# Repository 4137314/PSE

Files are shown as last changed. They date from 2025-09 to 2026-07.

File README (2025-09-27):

PSE - Power Supply Emulator
===========================

Version: 1.0
Author: 4137314
License: GNU General Public License v3.0

Purpose
-------
PSE is a KiCad project designed to emulate power supply circuits
for testing and prototyping purposes. It includes both schematic
and PCB layout files suitable for educational and development use.

Installation
------------
To obtain the project, clone the repository using Git:

    git clone https://github.com/4137314/PSE.git
    cd PSE

Open the file "PSE.kicad_pro" in KiCad to access the full project.

Usage
-----
- Inspect the schematic via "PSE.kicad_sch".
- Review the PCB layout in "PSE.kicad_pcb".
- Generate manufacturing files (Gerber, BOM, Drill) if needed.

Ensure all libraries and footprints referenced by the project are
available in your KiCad environment.

License
-------
This project is licensed under the GNU General Public License v3.0.
Refer to the LICENSE file in this repository for the full license text.

Reporting Bugs / Contributing
-----------------------------
Report bugs or suggest improvements via GitHub Issues. Contributions
are welcome under the same GPLv3 license.

Contact
-------
4137314
https://github.com/4137314/PSE

=======================================================================

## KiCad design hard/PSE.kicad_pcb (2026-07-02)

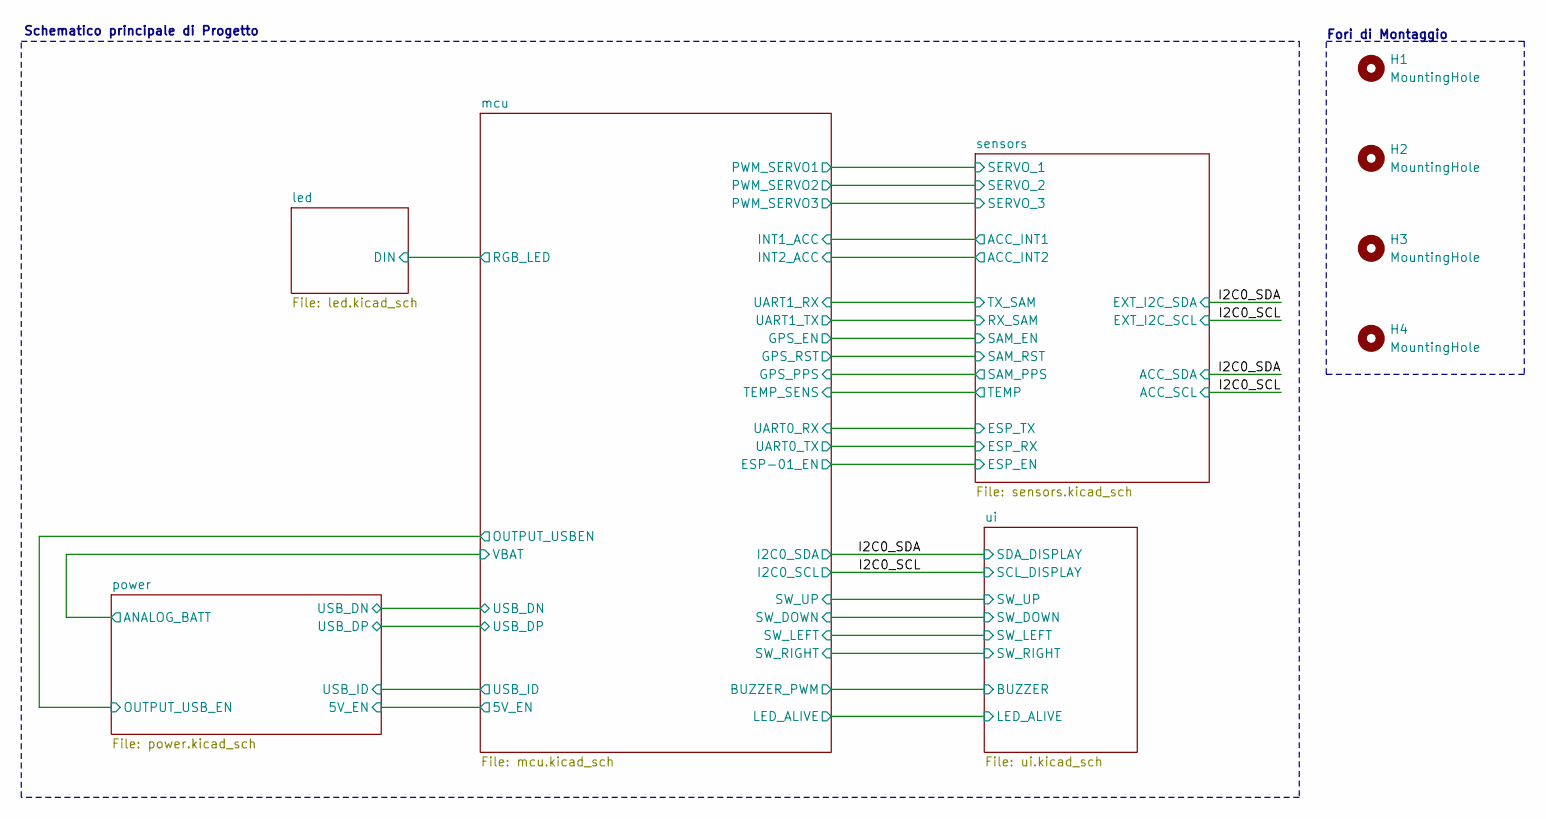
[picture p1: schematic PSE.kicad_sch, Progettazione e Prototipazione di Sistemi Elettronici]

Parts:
H1, H2, H3, H4: MountingHole; MountingHole_3.2mm_M3_Pad_Via

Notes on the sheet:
Fori di Montaggio
Schematico principale di Progetto

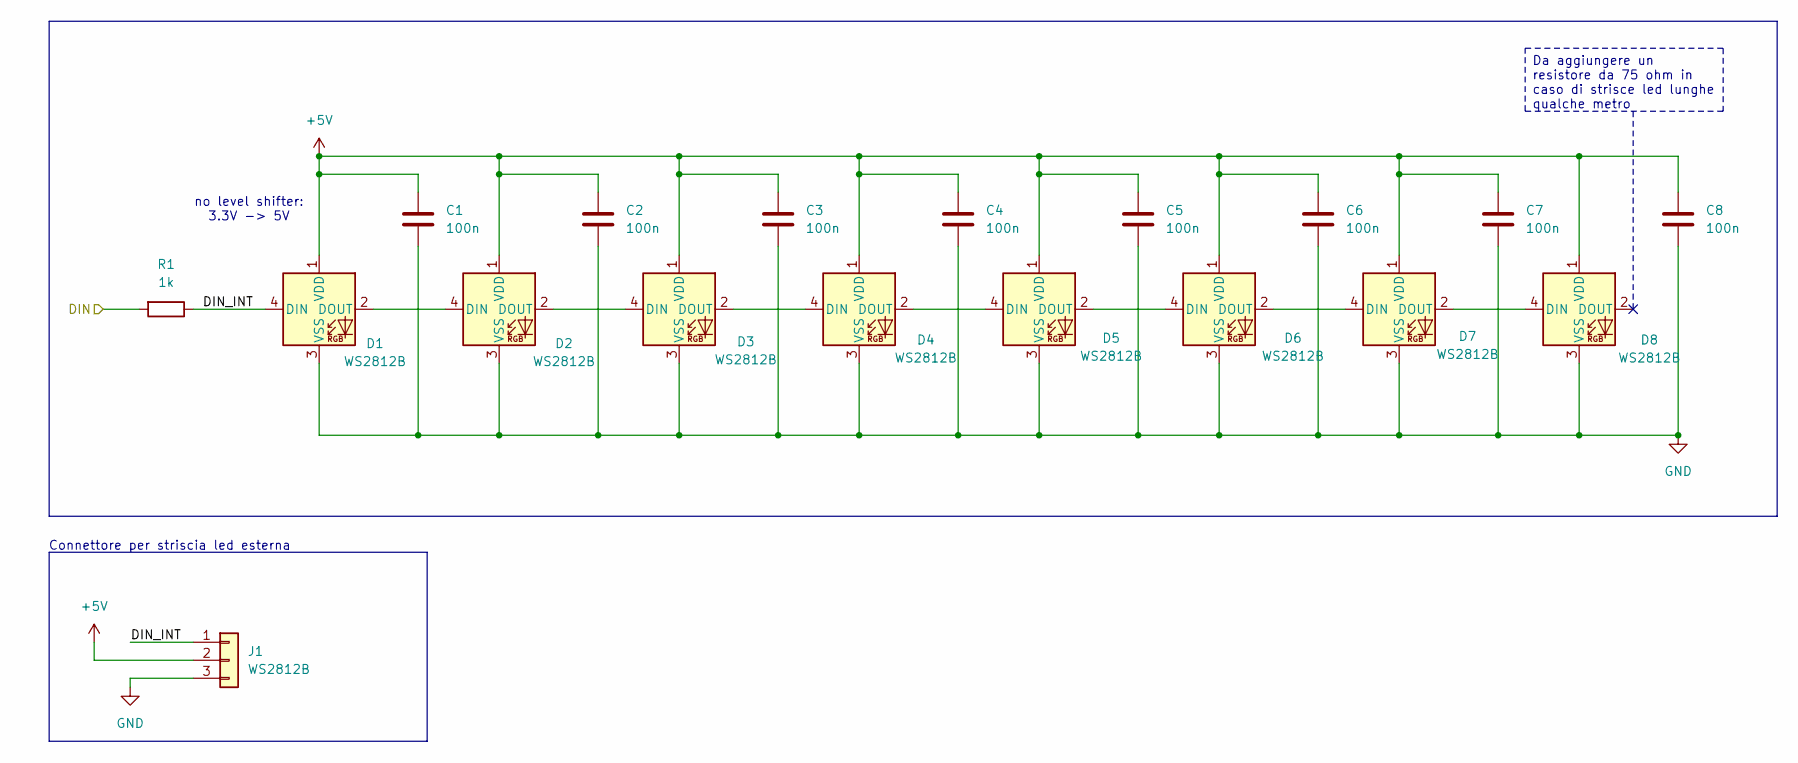
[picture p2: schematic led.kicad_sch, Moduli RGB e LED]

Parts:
C1, C2, C3, C4, C5, C6, C7, C8: 100n; C_0603_1608Metric
D1, D2, D3, D4, D5, D6, D7, D8: WS2812B; LED_WS2812B_PLCC4_5.0x5.0mm_P3.2mm
J1: WS2812B; PinHeader_1x03_P2.54mm_Vertical
R1: 1k; R_0603_1608Metric

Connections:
+5V: C1.1, C2.1, C3.1, C4.1, C5.1, C6.1, C7.1, C8.1, D1.1 (VDD), D2.1 (VDD), D3.1 (VDD), D4.1 (VDD), D5.1 (VDD), D6.1 (VDD), D7.1 (VDD), D8.1 (VDD), J1.2; also elsewhere on the board
/led/DIN: R1.2; also elsewhere on the board
/led/DIN_INT: D1.4 (DIN), J1.1, R1.1
GND: C1.2, C2.2, C3.2, C4.2, C5.2, C6.2, C7.2, C8.2, D1.3 (VSS), D2.3 (VSS), D3.3 (VSS), D4.3 (VSS), D5.3 (VSS), D6.3 (VSS), D7.3 (VSS), D8.3 (VSS), J1.3; also elsewhere on the board
unnamed: D1.2 (DOUT), D2.4 (DIN)
unnamed: D2.2 (DOUT), D3.4 (DIN)
unnamed: D3.2 (DOUT), D4.4 (DIN)
unnamed: D4.2 (DOUT), D5.4 (DIN)
unnamed: D5.2 (DOUT), D6.4 (DIN)
unnamed: D6.2 (DOUT), D7.4 (DIN)
unnamed: D7.2 (DOUT), D8.4 (DIN)

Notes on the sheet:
no level shifter: 3.3V -> 5V
Connettore per striscia led esterna
Da aggiungere un resistore da 75 ohm in caso di strisce led lunghe qualche metro

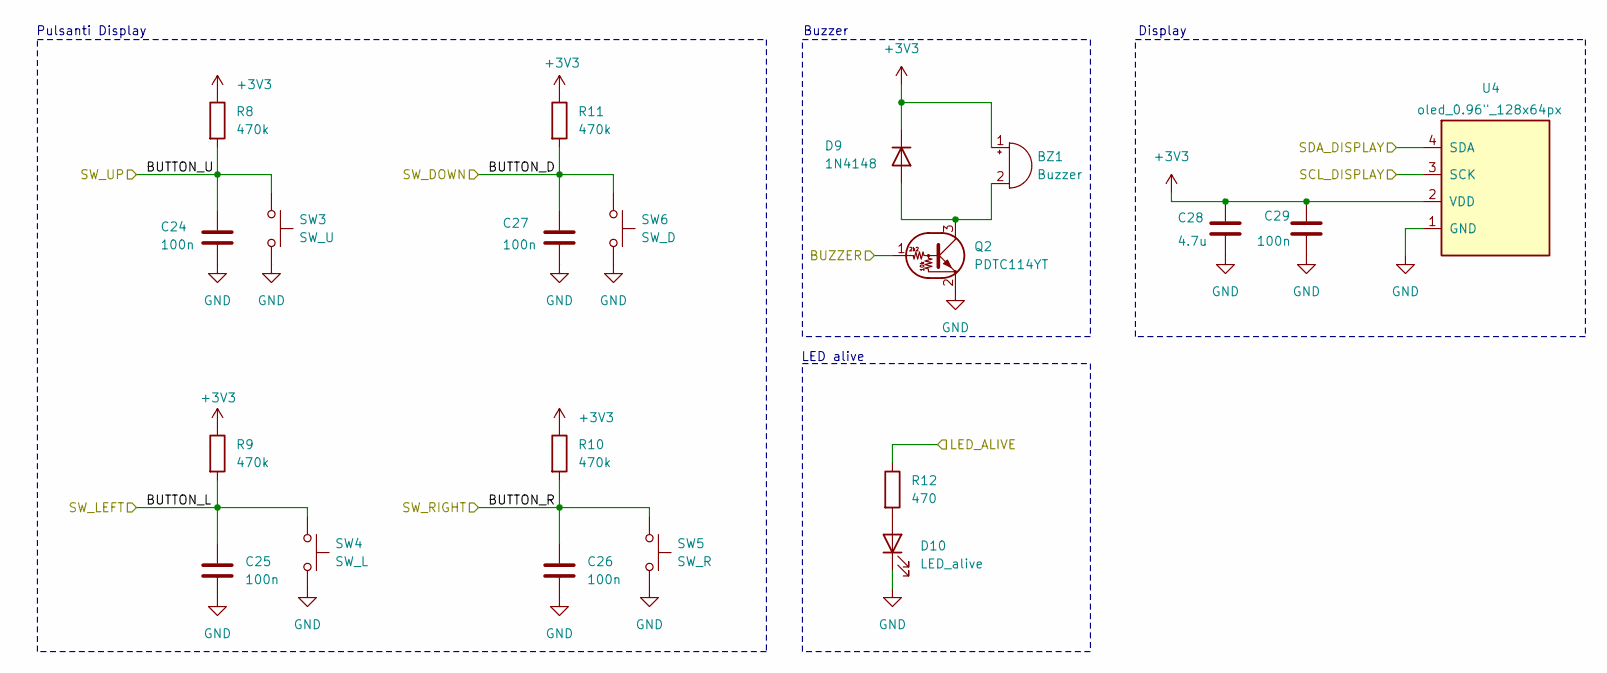
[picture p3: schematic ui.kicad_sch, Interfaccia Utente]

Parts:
BZ1: Buzzer; Buzzer_12x9.5RM7.6
C24, C25, C26, C27, C29: 100n; C_0603_1608Metric
C28: 4.7u; C_0603_1608Metric
D9: 1N4148; D_SOD-123
D10: LED_alive; LED_0603_1608Metric
Q2: PDTC114YT; SOT-23
R8, R9, R10, R11: 470k; R_0603_1608Metric
R12: 470; R_0603_1608Metric
SW3: SW_U; SW_SPST_EVQP0
SW4: SW_L; SW_SPST_EVQP0
SW5: SW_R; SW_SPST_EVQP0
SW6: SW_D; SW_SPST_EVQP0
U4: oled_0.96"_128x64px; PinHeader_1x04_P2.54mm_Vertical

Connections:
+3V3: BZ1.1 (+), C28.1, C29.1, D9.1 (K), R8.1, R9.1, R10.1, R11.1, U4.2 (VDD); also elsewhere on the board
/I2C0_SCL: U4.3 (SCK); also elsewhere on the board
/I2C0_SDA: U4.4 (SDA); also elsewhere on the board
/mcu/BUZZER_PWM: Q2.1 (B); also elsewhere on the board
/mcu/LED_ALIVE: R12.1; also elsewhere on the board
/ui/BUTTON_D: C27.1, R11.2, SW6.1; also elsewhere on the board
/ui/BUTTON_L: C25.1, R9.2, SW4.1; also elsewhere on the board
/ui/BUTTON_R: C26.1, R10.2, SW5.1; also elsewhere on the board
/ui/BUTTON_U: C24.1, R8.2, SW3.1; also elsewhere on the board
GND: C24.2, C25.2, C26.2, C27.2, C28.2, C29.2, D10.1 (K), Q2.2 (E), SW3.2, SW4.2, SW5.2, SW6.2, U4.1 (GND); also elsewhere on the board
unnamed: BZ1.2 (-), D9.2 (A), Q2.3 (C)
unnamed: D10.2 (A), R12.2

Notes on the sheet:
Pulsanti Display
Buzzer
Display
LED alive

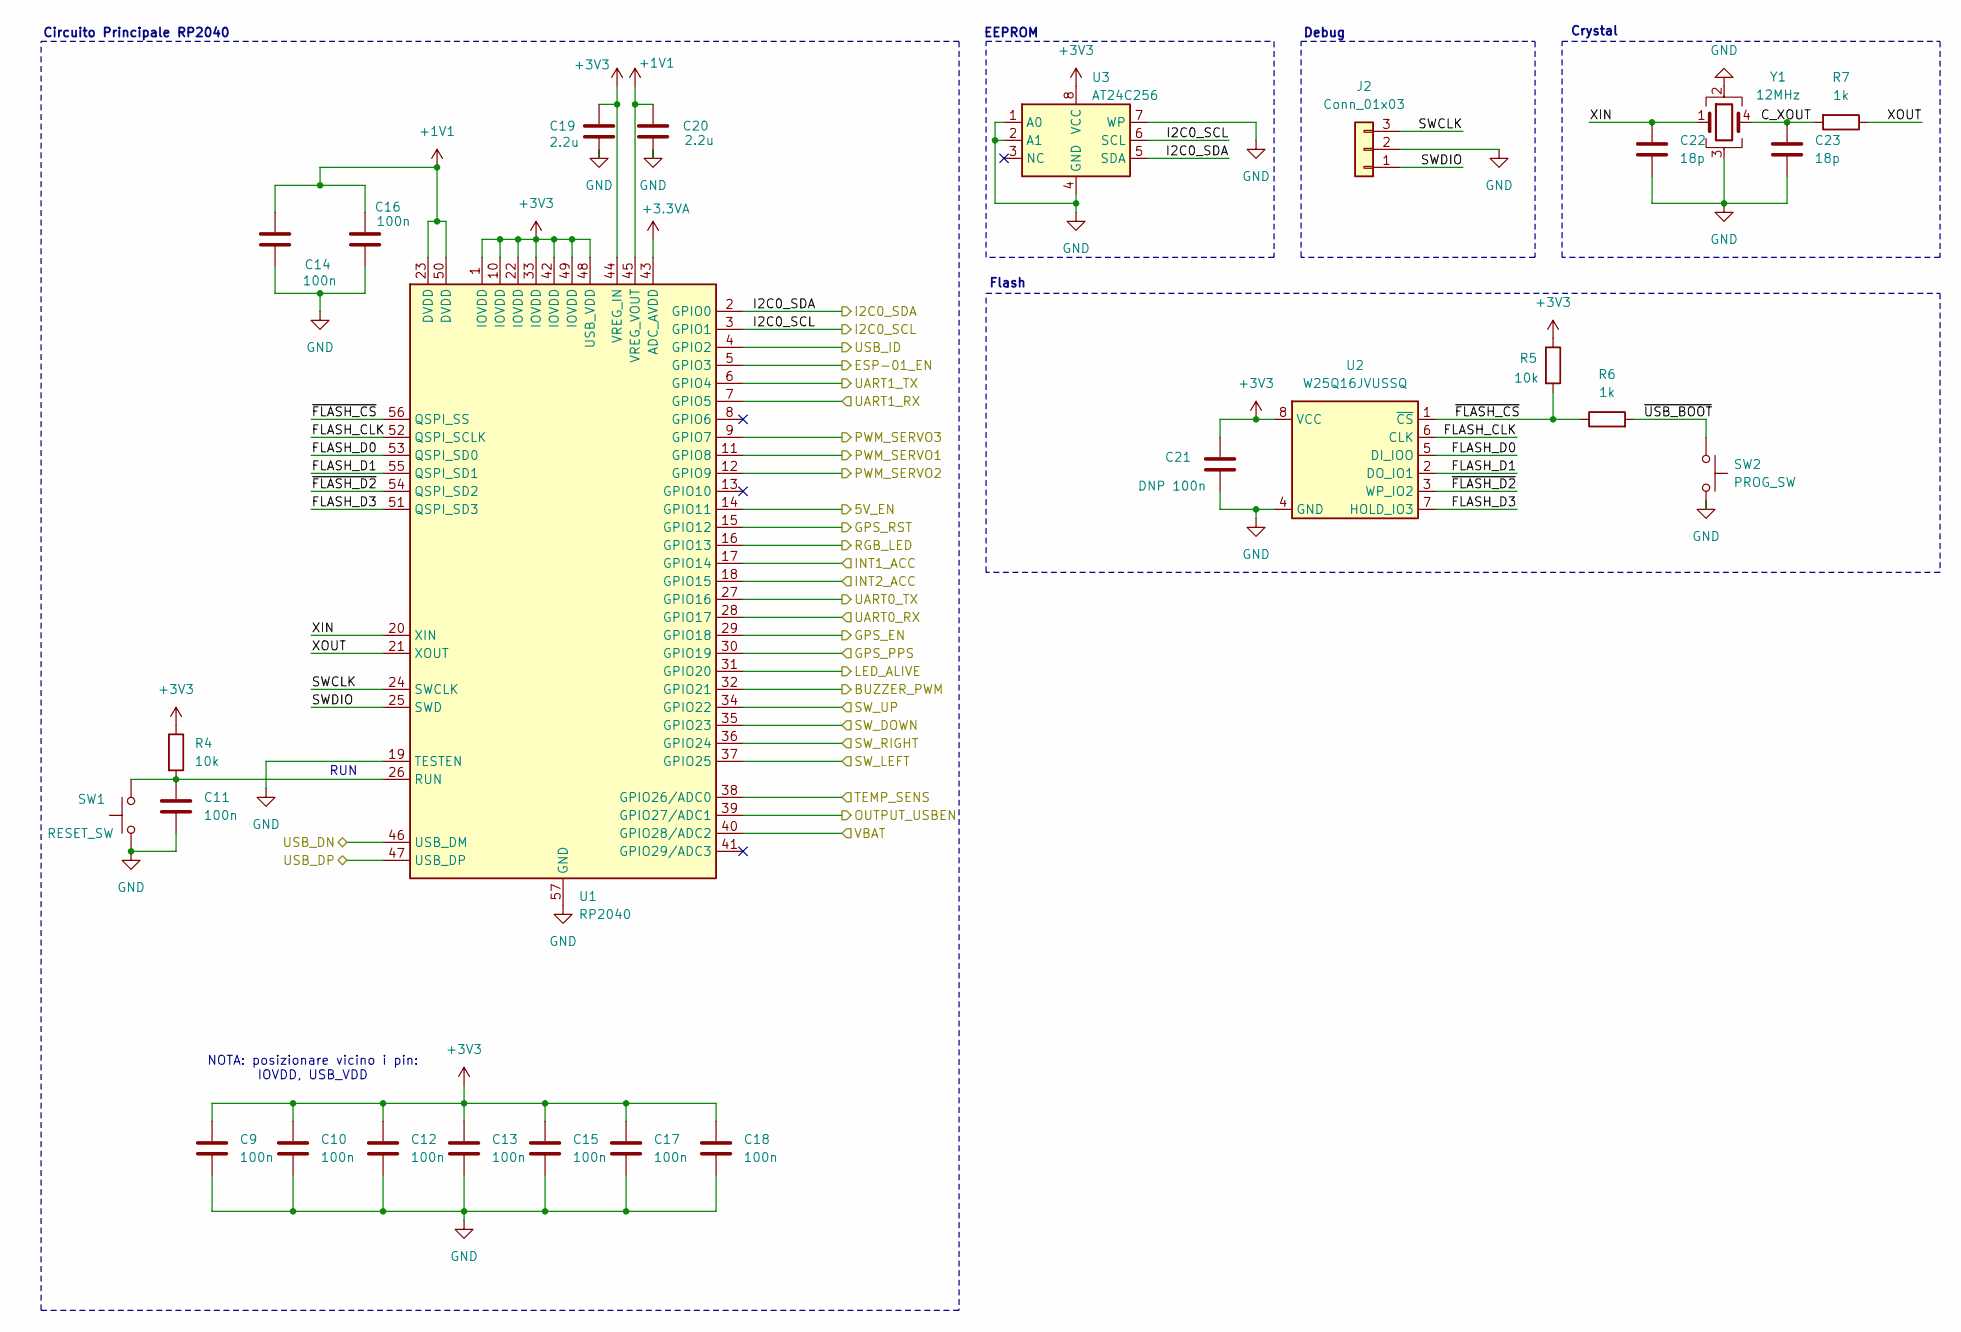
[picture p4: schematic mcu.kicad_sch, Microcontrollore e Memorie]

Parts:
C9, C10, C11, C12, C13, C14, C15, C16, C17, C18: 100n; C_0603_1608Metric
C19, C20: 2.2u; C_0603_1608Metric
C21: DNP 100n; C_0603_1608Metric
C22, C23: 18p; C_0603_1608Metric
J2: Conn_01x03; PinHeader_1x03_P2.54mm_Vertical
R4, R5: 10k; R_0603_1608Metric
R6, R7: 1k; R_0603_1608Metric
SW1: RESET_SW; SW_SPST_EVQP0
SW2: PROG_SW; SW_SPST_EVQP0
U1: RP2040; QFN-56-1EP_7x7mm_P0.4mm_EP3.2x3.2mm
U2: W25Q16JVUSSQ; SOIC-8_5.3x5.3mm_P1.27mm
U3: AT24C256; SOIC-8_3.9x4.9mm_P1.27mm
Y1: 12MHz; Crystal_SMD_3225-4Pin_3.2x2.5mm_HandSoldering

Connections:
+1V1: C14.1, C16.1, C20.1, U1.23 (DVDD), U1.45 (VREG_VOUT), U1.50 (DVDD)
+3.3VA: U1.43 (ADC_AVDD); also elsewhere on the board
+3V3: C9.1, C10.1, C12.1, C13.1, C15.1, C17.1, C18.1, C19.1, C21.1, R4.1, R5.1, U1.1 (IOVDD), U1.10 (IOVDD), U1.22 (IOVDD), U1.33 (IOVDD), U1.42 (IOVDD), U1.44 (VREG_IN), U1.48 (USB_VDD), U1.49 (IOVDD), U2.8 (VCC), U3.8 (VCC); also elsewhere on the board
/I2C0_SCL: U1.3 (GPIO1), U3.6 (SCL); also elsewhere on the board
/I2C0_SDA: U1.2 (GPIO0), U3.5 (SDA); also elsewhere on the board
/led/DIN: U1.16 (GPIO13); also elsewhere on the board
/mcu/5V_EN: U1.14 (GPIO11); also elsewhere on the board
/mcu/BUZZER_PWM: U1.32 (GPIO21); also elsewhere on the board
/mcu/C_XOUT: C23.1, R7.2, Y1.4
/mcu/ESP-01_EN: U1.5 (GPIO3); also elsewhere on the board
/mcu/FLASH_CLK: U1.52 (QSPI_SCLK), U2.6 (CLK)
/mcu/FLASH_D0: U1.53 (QSPI_SD0), U2.5 (DI_IOO)
/mcu/FLASH_D1: U1.55 (QSPI_SD1), U2.2 (DO_IO1)
/mcu/FLASH_D3: U1.51 (QSPI_SD3), U2.7 (HOLD_IO3)
/mcu/GPS_EN: U1.29 (GPIO18); also elsewhere on the board
/mcu/GPS_PPS: U1.30 (GPIO19); also elsewhere on the board
/mcu/GPS_RST: U1.15 (GPIO12); also elsewhere on the board
/mcu/INT1_ACC: U1.17 (GPIO14); also elsewhere on the board
/mcu/INT2_ACC: U1.18 (GPIO15); also elsewhere on the board
/mcu/LED_ALIVE: U1.31 (GPIO20); also elsewhere on the board
/mcu/OUTPUT_USBEN: U1.39 (GPIO27/ADC1); also elsewhere on the board
/mcu/PWM_SERVO1: U1.11 (GPIO8); also elsewhere on the board
/mcu/PWM_SERVO2: U1.12 (GPIO9); also elsewhere on the board
/mcu/PWM_SERVO3: U1.9 (GPIO7); also elsewhere on the board
/mcu/SWCLK: J2.3, U1.24 (SWCLK)
/mcu/SWDIO: J2.1, U1.25 (SWD)
/mcu/TEMP_SENS: U1.38 (GPIO26/ADC0); also elsewhere on the board
/mcu/UART0_RX: U1.28 (GPIO17); also elsewhere on the board
/mcu/UART0_TX: U1.27 (GPIO16); also elsewhere on the board
/mcu/USB_DN: U1.46 (USB_DM); also elsewhere on the board
/mcu/USB_DP: U1.47 (USB_DP); also elsewhere on the board
/mcu/USB_ID: U1.4 (GPIO2); also elsewhere on the board
/mcu/VBAT: U1.40 (GPIO28/ADC2); also elsewhere on the board
/mcu/XIN: C22.1, U1.20 (XIN), Y1.1
/mcu/XOUT: R7.1, U1.21 (XOUT)
/mcu/~FLASH_CS: R5.2, R6.1, U1.56 (QSPI_SS), U2.1 (~CS)
/mcu/~FLASH_D2: U1.54 (QSPI_SD2), U2.3 (WP_IO2)
/mcu/~USB_BOOT: R6.2, SW2.1
/sensors/UART_RX: U1.7 (GPIO5); also elsewhere on the board
/sensors/UART_TX: U1.6 (GPIO4); also elsewhere on the board
/ui/BUTTON_D: U1.35 (GPIO23); also elsewhere on the board
/ui/BUTTON_L: U1.37 (GPIO25); also elsewhere on the board
/ui/BUTTON_R: U1.36 (GPIO24); also elsewhere on the board
/ui/BUTTON_U: U1.34 (GPIO22); also elsewhere on the board
GND: C9.2, C10.2, C11.2, C12.2, C13.2, C14.2, C15.2, C16.2, C17.2, C18.2, C19.2, C20.2, C21.2, C22.2, C23.2, J2.2, SW1.1, SW2.2, U1.19 (TESTEN), U1.57 (GND), U2.4 (GND), U3.1 (A0), U3.2 (A1), U3.4 (GND), U3.7 (WP), Y1.2, Y1.3; also elsewhere on the board
unnamed: C11.1, R4.2, SW1.2, U1.26 (RUN)

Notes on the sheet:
Circuito Principale RP2040
Flash
Debug
NOTA: posizionare vicino i pin: IOVDD, USB_VDD
Crystal
RUN
EEPROM

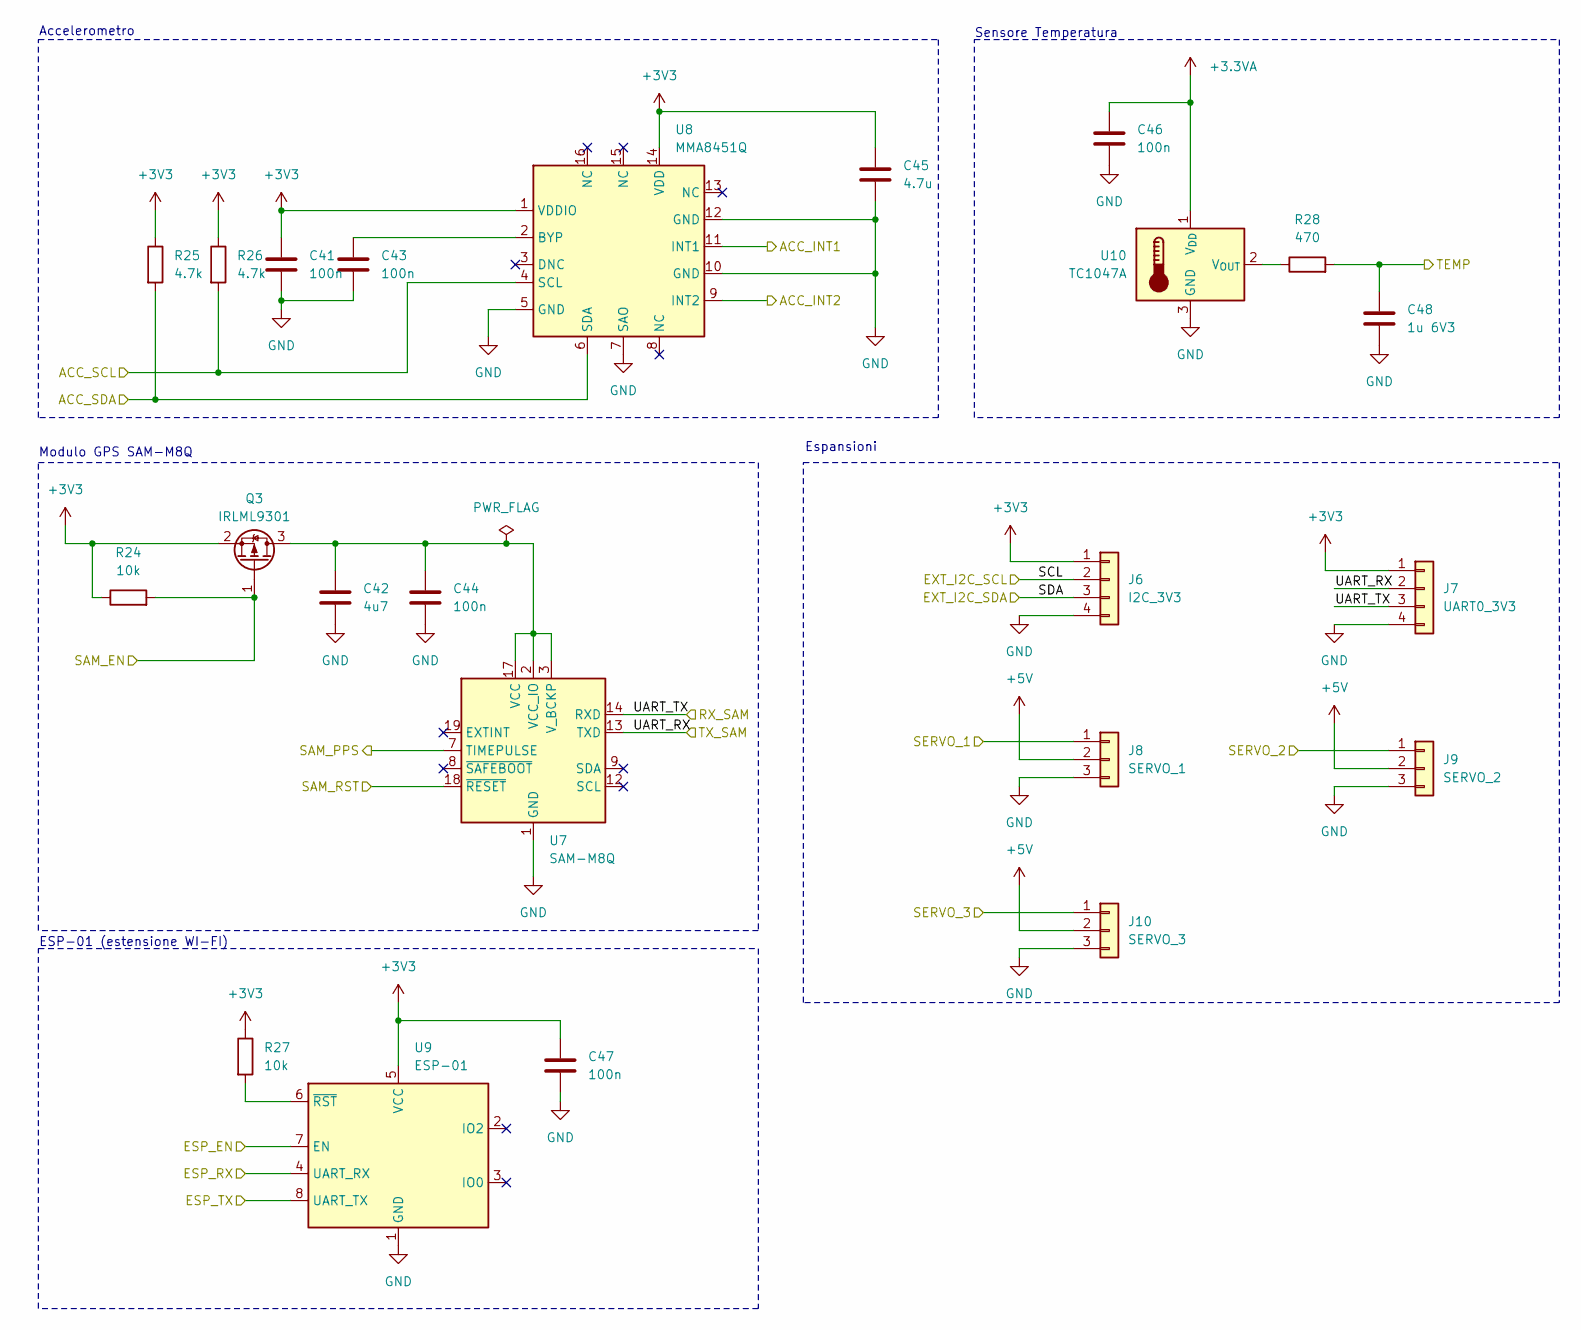
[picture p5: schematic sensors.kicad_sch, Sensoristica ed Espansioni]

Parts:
C41, C43, C44, C46, C47: 100n; C_0603_1608Metric
C42: 4u7; C_0603_1608Metric
C45: 4.7u; C_0603_1608Metric
C48: 1u 6V3; C_0603_1608Metric
J6: I2C_3V3; JST_XH_B4B-XH-A_1x04_P2.50mm_Vertical
J7: UART0_3V3; JST_XH_B4B-XH-A_1x04_P2.50mm_Vertical
J8: SERVO_1; PinHeader_1x03_P2.54mm_Vertical
J9: SERVO_2; PinHeader_1x03_P2.54mm_Vertical
J10: SERVO_3; PinHeader_1x03_P2.54mm_Vertical
Q3: IRLML9301; SOT-23
R24, R27: 10k; R_0603_1608Metric
R25, R26: 4.7k; R_0603_1608Metric
R28: 470; R_0603_1608Metric
U7: SAM-M8Q; ublox_SAM-M8Q
U8: MMA8451Q; QFN16_FRE
U9: ESP-01; PinSocket_2x04_P2.54mm_Vertical
U10: TC1047A; SOT-23

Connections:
+3.3VA: C46.1, U10.1 (V_{DD}); also elsewhere on the board
+3V3: C41.1, C45.1, C47.1, J6.1, J7.1, Q3.2 (S), R24.1, R25.1, R26.1, R27.1, U8.1 (VDDIO), U8.14 (VDD), U9.5 (VCC); also elsewhere on the board
+5V: J8.2, J9.2, J10.2; also elsewhere on the board
/I2C0_SCL: J6.2, R26.2, U8.4 (SCL); also elsewhere on the board
/I2C0_SDA: J6.3, R25.2, U8.6 (SDA); also elsewhere on the board
/mcu/ESP-01_EN: U9.7 (EN); also elsewhere on the board
/mcu/GPS_EN: Q3.1 (G), R24.2; also elsewhere on the board
/mcu/GPS_PPS: U7.7 (TIMEPULSE); also elsewhere on the board
/mcu/GPS_RST: U7.18 (~RESET); also elsewhere on the board
/mcu/INT1_ACC: U8.11 (INT1); also elsewhere on the board
/mcu/INT2_ACC: U8.9 (INT2); also elsewhere on the board
/mcu/PWM_SERVO1: J8.1; also elsewhere on the board
/mcu/PWM_SERVO2: J9.1; also elsewhere on the board
/mcu/PWM_SERVO3: J10.1; also elsewhere on the board
/mcu/TEMP_SENS: C48.1, R28.2; also elsewhere on the board
/mcu/UART0_RX: U9.8 (UART_TX); also elsewhere on the board
/mcu/UART0_TX: U9.4 (UART_RX); also elsewhere on the board
/sensors/UART_RX: J7.2, U7.13 (TXD); also elsewhere on the board
/sensors/UART_TX: J7.3, U7.14 (RXD); also elsewhere on the board
GND: C41.2, C42.2, C43.2, C44.2, C45.2, C46.2, C47.2, C48.2, J6.4, J7.4, J8.3, J9.3, J10.3, U7.1 (GND), U8.5 (GND), U8.7 (SAO), U8.10 (GND), U8.12 (GND), U9.1 (GND), U10.3 (GND); also elsewhere on the board
unnamed: C42.1, C44.1, Q3.3 (D), U7.2 (VCC_IO), U7.3 (V_BCKP), U7.17 (VCC)
unnamed: C43.1, U8.2 (BYP)
unnamed: R27.2, U9.6 (~RST)
unnamed: R28.1, U10.2 (V_{OUT})

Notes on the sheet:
Sensore Temperatura
Accelerometro
ESP-01 (estensione WI-FI)
Modulo GPS SAM-M8Q
Espansioni

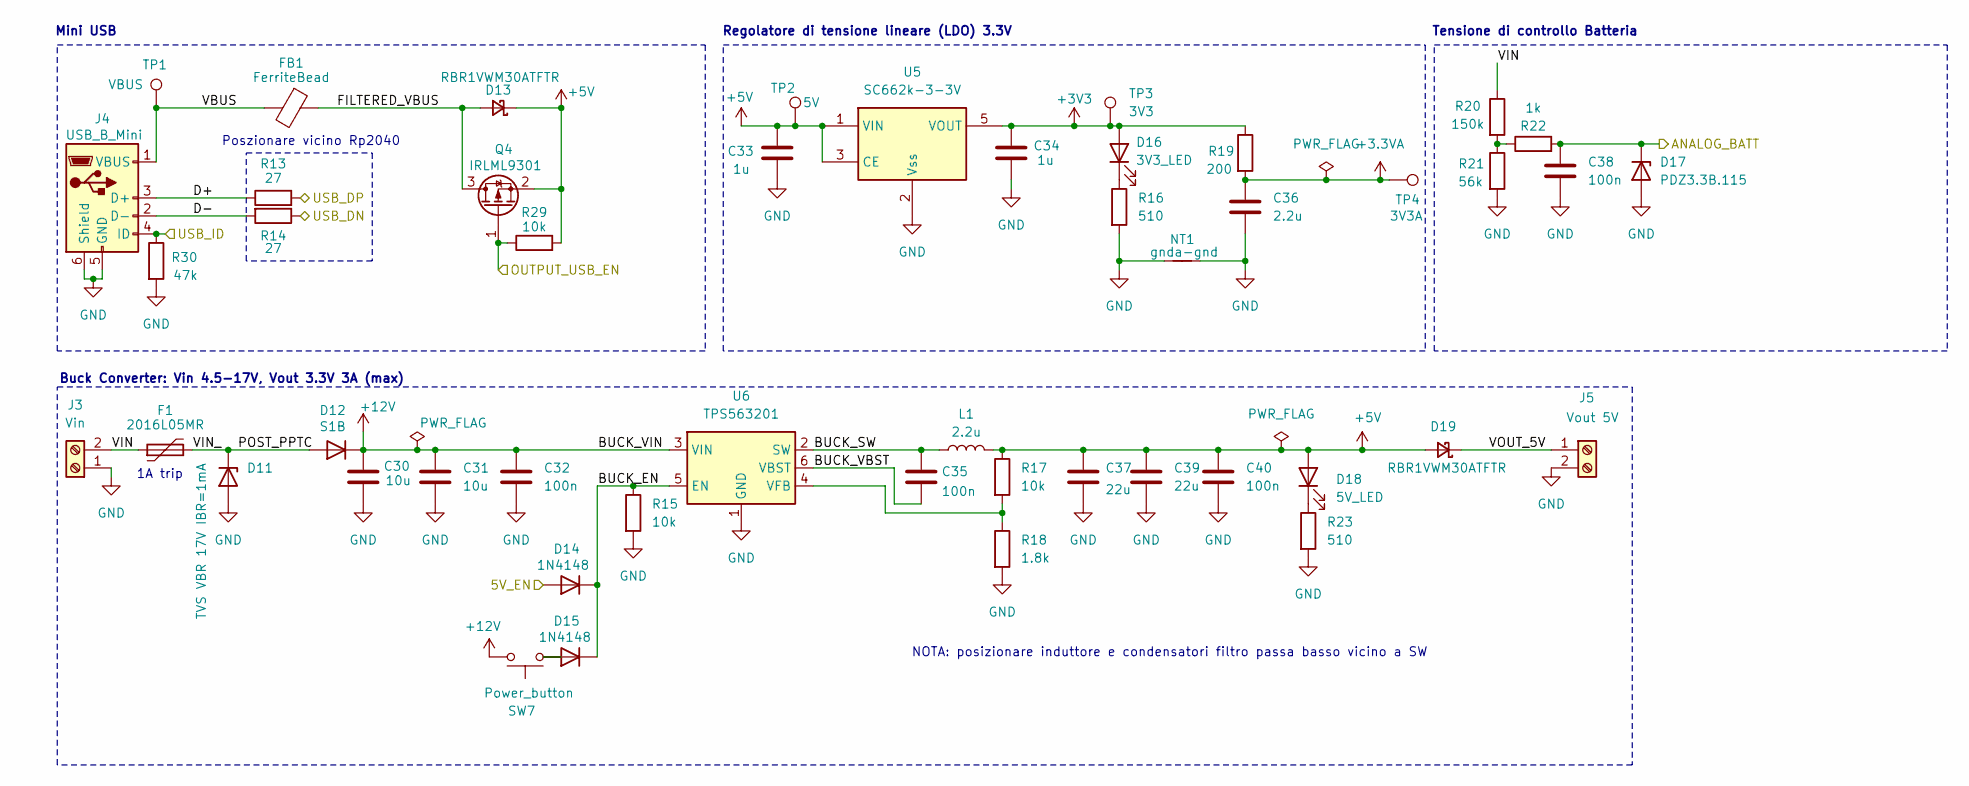
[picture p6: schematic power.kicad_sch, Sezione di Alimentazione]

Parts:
C30, C31: 10u; C_0805_2012Metric
C32, C35, C38, C40: 100n; C_0603_1608Metric
C33, C34: 1u; C_0603_1608Metric
C36: 2.2u; C_0603_1608Metric
C37, C39: 22u; C_0805_2012Metric
D11: TVS VBR 17V IBR=1mA; D_SMA
D12: S1B; D_SMA
D13, D19: RBR1VWM30ATFTR; D_SOD-123
D14, D15: 1N4148; D_SOD-123
D16: 3V3_LED; LED_0805_2012Metric
D17: PDZ3.3B.115; D_SOD-323_HandSoldering
D18: 5V_LED; LED_0805_2012Metric
F1: 2016L05MR; Fuse_1206_3216Metric
FB1: FerriteBead; C_0805_2012Metric
J3: Vin; TerminalBlock_bornier-2_P5.08mm
J4: USB_B_Mini; USB_Mini-B_Wuerth_65100516121_Horizontal
J5: Vout 5V; TerminalBlock_bornier-2_P5.08mm
L1: 2.2u; C_0603_1608Metric
NT1: gnda-gnd; NetTie-2_SMD_Pad0.5mm
Q4: IRLML9301; SOT-23
R13, R14: 27; R_0603_1608Metric
R15, R17, R29: 10k; R_0603_1608Metric
R16, R23: 510; R_0603_1608Metric
R18: 1.8k; R_0603_1608Metric
R19: 200; R_0603_1608Metric
R20: 150k; R_0603_1608Metric
R21: 56k; R_0603_1608Metric
R22: 1k; R_0603_1608Metric
R30: 47k; R_0603_1608Metric
SW7: Power_button; SW_SPST_EVQP0
TP1: VBUS; TestPoint_THTPad_D1.5mm_Drill0.7mm
TP2: 5V; TestPoint_THTPad_D1.5mm_Drill0.7mm
TP3: 3V3; TestPoint_THTPad_D1.5mm_Drill0.7mm
TP4: 3V3A; TestPoint_THTPad_D1.5mm_Drill0.7mm
U5: SC662k-3-3V; SOT-23-5_HandSoldering
U6: TPS563201; SOT-23-6

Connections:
+3.3VA: C36.1, R19.2, TP4.1; also elsewhere on the board
+3V3: C34.1, D16.2 (A), R19.1, TP3.1, U5.5 (VOUT); also elsewhere on the board
+5V: C33.1, C37.1, C39.1, C40.1, D13.1 (K), D18.2 (A), D19.2 (A), L1.2, Q4.2 (S), R17.1, R29.2, TP2.1, U5.1 (VIN), U5.3 (CE); also elsewhere on the board
+12V: C30.1, C31.1, C32.1, D12.1 (K), SW7.2, U6.3 (VIN)
/mcu/5V_EN: D14.2 (A); also elsewhere on the board
/mcu/OUTPUT_USBEN: Q4.1 (G), R29.1; also elsewhere on the board
/mcu/USB_DN: R14.1; also elsewhere on the board
/mcu/USB_DP: R13.2; also elsewhere on the board
/mcu/USB_ID: J4.4 (ID), R30.1; also elsewhere on the board
/mcu/VBAT: C38.1, D17.1 (K), R22.2; also elsewhere on the board
/power/BUCK_EN: D14.1 (K), D15.1 (K), R15.1, U6.5 (EN)
/power/BUCK_SW: C35.2, L1.1, U6.2 (SW)
/power/BUCK_VBST: C35.1, U6.6 (VBST)
/power/D+: J4.3 (D+), R13.1
/power/D-: J4.2 (D-), R14.2
/power/FILTERED_VBUS: D13.2 (A), FB1.1, Q4.3 (D)
/power/POST_PPTC: D11.1 (K), D12.2 (A), F1.2
/power/VBUS: FB1.2, J4.1 (VBUS), TP1.1
/power/VIN: F1.1, J3.2, R20.1
/power/VOUT_5V: D19.1 (K), J5.1
GND: C30.2, C31.2, C32.2, C33.2, C34.2, C36.2, C37.2, C38.2, C39.2, C40.2, D11.2 (A), D17.2 (A), J3.1, J4.5 (GND), J4.6 (Shield), J5.2, NT1.1, NT1.2, R15.2, R16.2, R18.2, R21.2, R23.2, R30.2, U5.2 (Vss), U6.1 (GND); also elsewhere on the board
unnamed: D15.2 (A), SW7.1
unnamed: D16.1 (K), R16.1
unnamed: D18.1 (K), R23.1
unnamed: R20.2, R21.1, R22.1
unnamed: R17.2, R18.1, U6.4 (VFB)

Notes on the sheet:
Tensione di controllo Batteria
Regolatore di tensione lineare (LDO) 3.3V
Buck Converter: Vin 4.5-17V, Vout 3.3V 3A (max)
Poszionare vicino Rp2040
NOTA: posizionare induttore e condensatori filtro passa basso vicino a SW
1A trip
Mini USB

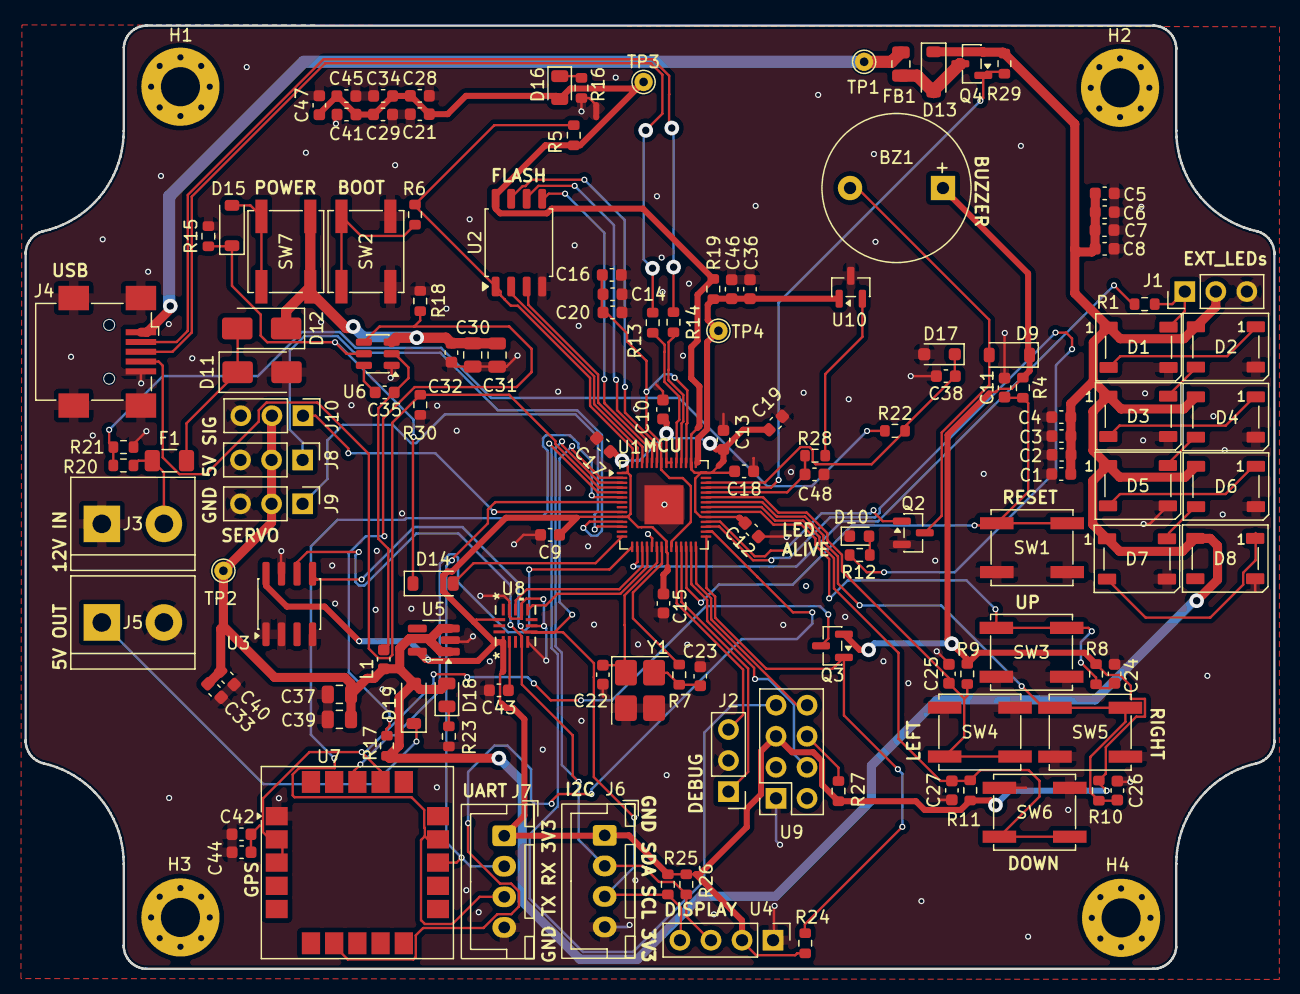
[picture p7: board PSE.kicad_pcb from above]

Board: 2 copper layers, 102.2 x 77.2 mm, 139 parts (0 on the bottom side), 77 nets.

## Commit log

2026-06-18 update - se ci sono errori prima della consegna -> (flag prima di sto commit funzionava tutto)
    [sensors.kicad_sch]
2026-07-02 correzione layout bottom
    [PSE.kicad_pcb]
